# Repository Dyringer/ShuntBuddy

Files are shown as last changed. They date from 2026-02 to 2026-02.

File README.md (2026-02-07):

# ShuntBuddy ⚡

<table>
  <tr>
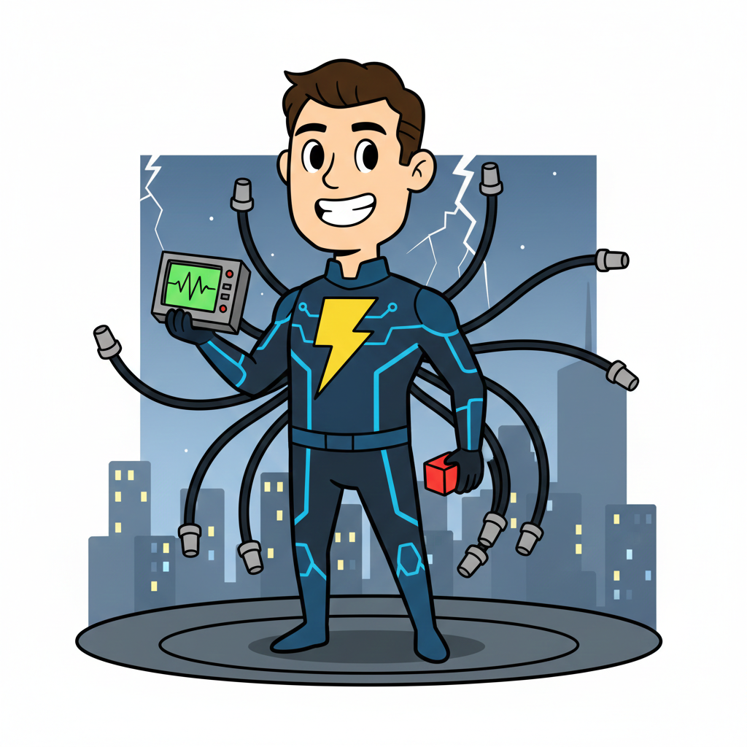
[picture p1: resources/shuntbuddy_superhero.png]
    <td>  </td>
  </tr>
</table>

**ShuntBuddy** is an active oscilloscope adapter designed for precise current measurement. It eliminates the hassle of measuring high-side current by converting the voltage drop across a shunt resistor into a buffered, amplified signal that your oscilloscope can easily display.

## How it Works

ShuntBuddy sits between your power supply and your load. It uses the **Texas Instruments INA225**—a fully integrated, programmable gain difference amplifier. The device captures the tiny voltage drop across an internal 10mΩ shunt and scales it up.

Simply connect ShuntBuddy to your scope via a BNC cable, power it via USB-C, and your current readings appear as a voltage signal.

---
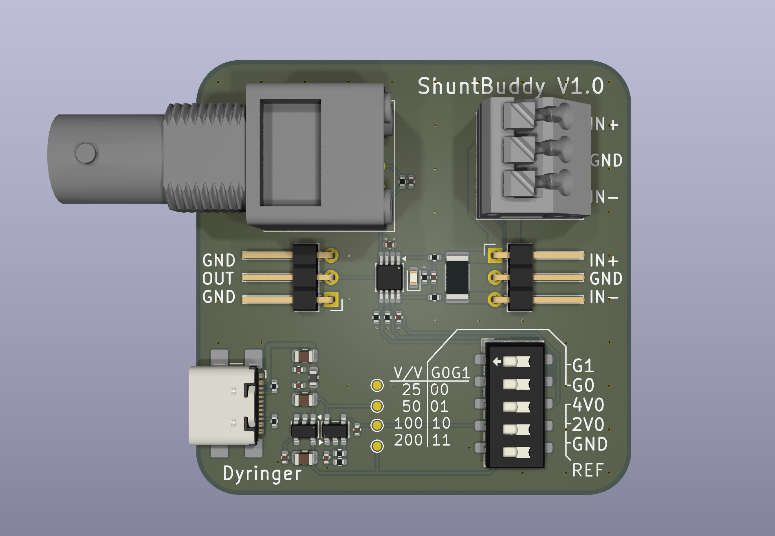
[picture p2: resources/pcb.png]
PCB

---

## Technical Specifications

* **Amplifier:** INA225 (High-precision, integrated gain resistors)
* **Input Shunt:** 10mΩ 
* **Power Input:** USB-C (5V)
* **Output:** BNC (Compatible with all standard oscilloscopes)
* **Form Factor:** Current-to-Voltage Probe (acts like a x10 probe)

### Gain & Current Ranges

With the onboard **10mΩ shunt**, the following ranges are available via the DIP switch:

| Setting | Gain () | Scale Factor | Max Current (at 4V Output) |
| --- | --- | --- | --- |
| **G1** | 25 | 250 mV/A | **16.0 A** |
| **G2** | 50 | 500 mV/A | **8.0 A** |
| **G3** | 100 | 1 V/A | **4.0 A** |
| **G4** | 200 | 2 V/A | **2.0 A** |

---

## Configuration

### 1. Gain Selection (DIP Switch)

The INA225 allows you to hardware-configure the gain. This is useful for "zooming in" on low-power signals (G4) or measuring high-current surges (G1) without clipping the output.

### 2. Reference Voltage ()

You can shift the "zero" point of your measurement to handle different scenarios:

* **4V Reference:** Optimized for **Unidirectional** measurement (Current flowing from Source to Load). Provides the widest dynamic range for power consumption analysis.
* **2V Reference:** Optimized for **Bidirectional** measurement. This centers the zero point, allowing you to see both charging and discharging currents (positive and negative swings).

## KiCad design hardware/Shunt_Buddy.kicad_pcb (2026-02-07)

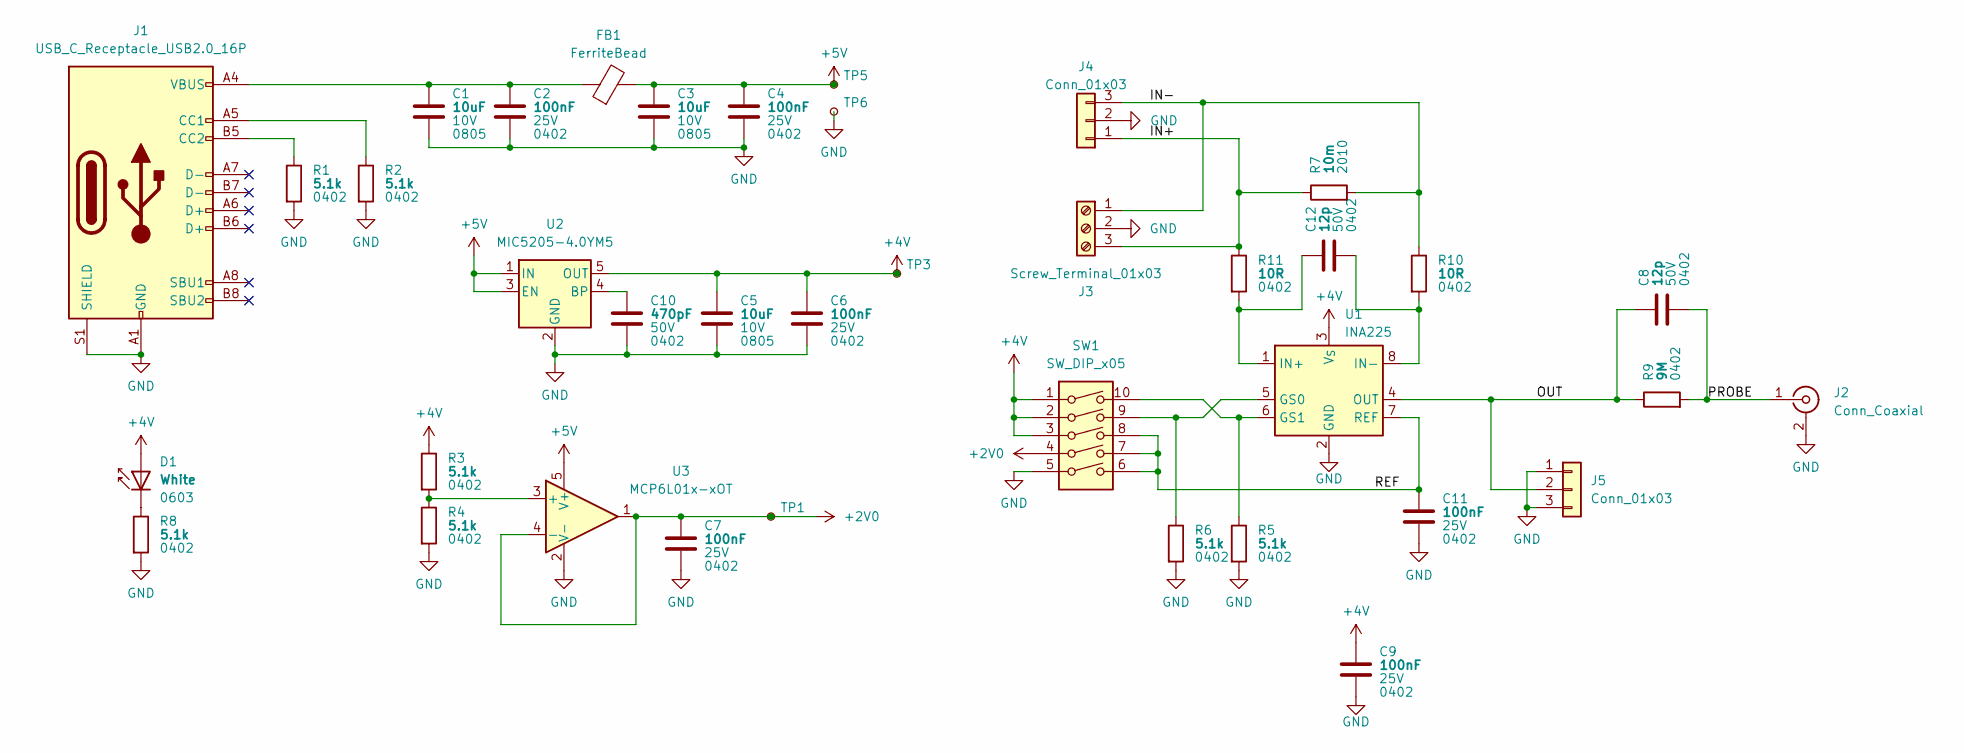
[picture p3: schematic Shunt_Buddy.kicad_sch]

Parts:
C1, C3, C5: 10uF; C_0805_2012Metric; Voltage 10V
C2, C4, C6, C7, C9, C11: 100nF; C_0402_1005Metric; Voltage 25V
C8, C12: 12p; C_0402_1005Metric; Voltage 50V
C10: 470pF; C_0402_1005Metric; Voltage 50V
D1: White; LED_0603_1608Metric
FB1: FerriteBead; L_0603_1608Metric
J1: USB_C_Receptacle_USB2.0_16P; USB_C_Receptacle_GCT_USB4110
J2: Conn_Coaxial; BNC_Amphenol_B6252HB-NPP3G-50_Horizontal
J3: Screw_Terminal_01x03; TerminalBlock_Degson_DG250-3.5-03P_1x03_P3.50mm_45Degree
J4, J5: Conn_01x03; PinHeader_1x03_P2.54mm_Horizontal
R1, R2, R3, R4, R5, R6, R8: 5.1k; R_0402_1005Metric
R7: 10m; R_2010_5025Metric
R9: 9M; R_0402_1005Metric
R10, R11: 10R; R_0402_1005Metric
SW1: SW_DIP_x05; SW_DIP_SPSTx05_Slide_6.7x14.26mm_W6.73mm_P2.54mm_LowProfile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
TP1, TP3, TP5, TP6: TestPoint_Small; TestPoint_Pad_D1.0mm
U1: INA225; VSSOP-8_3x3mm_P0.65mm
U2: MIC5205-4.0YM5; SOT-23-5
U3: MCP6L01x-xOT; SOT-23-5

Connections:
+2V0: C7.1, SW1.4, TP1.1 (1_1), U3.1, U3.4 (-)
+4V: C5.1, C6.1, C9.1, D1.2 (A), R3.1, SW1.1, SW1.2, SW1.3, TP3.1 (1_1), U1.3 (V_{S}), U2.5 (OUT)
+5V: C3.1, C4.1, FB1.2, TP5.1 (1_1), U2.1 (IN), U2.3 (EN), U3.5 (V+)
/IN+: J3.3, J4.1, R7.1, R11.1
/IN-: J3.1, J4.3, R7.2, R10.1
/OUT: C8.1, J5.2, R9.1, U1.4 (OUT)
/PROBE: C8.2, J2.1 (In), R9.2
/REF: C11.1, SW1.6, SW1.7, SW1.8, U1.7 (REF)
GND: C1.2, C2.2, C3.2, C4.2, C5.2, C6.2, C7.2, C9.2, C10.2, C11.2, J1.A1 (GND), J1.A12 (GND), J1.B1 (GND), J1.B12 (GND), J1.S1 (SHIELD), J2.2 (Ext), J3.2, J4.2, J5.1, J5.3, R1.2, R2.2, R4.2, R5.2, R6.2, R8.2, SW1.5, TP6.1 (1_1), U1.2 (GND), U2.2 (GND), U3.2 (V-)
unnamed: C1.1, C2.1, FB1.1, J1.A4 (VBUS), J1.A9 (VBUS), J1.B4 (VBUS), J1.B9 (VBUS)
unnamed: D1.1 (K), R8.1
unnamed: J1.A5 (CC1), R2.1
unnamed: J1.B5 (CC2), R1.1
unnamed: R6.1, SW1.9, U1.5 (GS0)
unnamed: R5.1, SW1.10, U1.6 (GS1)
unnamed: C12.1, R11.2, U1.1 (IN+)
unnamed: C12.2, R10.2, U1.8 (IN-)
unnamed: C10.1, U2.4 (BP)
unnamed: R3.2, R4.1, U3.3 (+)

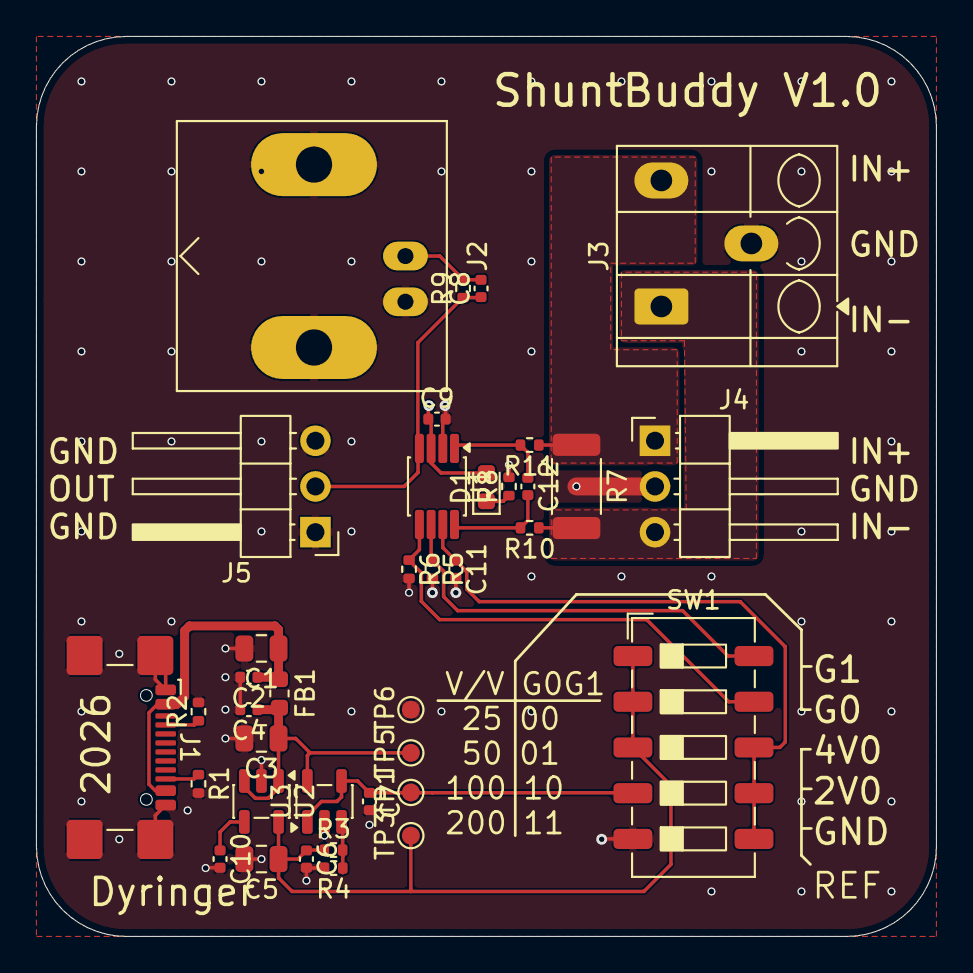
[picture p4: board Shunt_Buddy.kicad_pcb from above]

Board: 2 copper layers, 50.0 x 50.0 mm, 38 parts (0 on the bottom side), 19 nets.
